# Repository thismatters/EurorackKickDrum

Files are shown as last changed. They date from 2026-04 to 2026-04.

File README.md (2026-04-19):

# Kick Drum

The circuit here is an implementation the circuit in the [Moritz Klien kick drum video](https://www.youtube.com/watch?v=yz37Yz315eU) with all of the trappings to make it a proper module. The aforementioned video is extremely good and deserves a watch (along with all their other content, top notch). While the [Erica Synths kit](https://www.ericasynths.lv/shop/diy-kits-1/edu-diy-kick-drum/) has 7 knobs I have limited myself to 4 knobs: Decay, Pitch, Distortion, and Tone. The other 3 knobs are be present as screw-turn potentiometers accessible from the front panel for retuning the module.

The KiCAD project here uses the library/footprints [found in my companion repo](https://github.com/thismatters/EurorackKiCAD).

## Width

6hp on a standard 3U rack.

## Inputs

3 Jacks
- Gate
- Accent CV
- Pitch CV

4 Knobs:
- Decay
- Distortion
- Tone
- Pitch

3 Screw Pots (accessible from front):
- Tune Decay
- Tune Depth
- Max Pitch CV

## Outputs

1 Jack for audio output.

## Vendors

There are part numbers in the [BOM](kick-drum.csv) for many of the parts (not for basic passives though) at the following vendors:

* [Mouser](https://www.mouser.com): Needs no introduction. Get your ICs from here (or [digikey](https://www.digikey.com)).
* [Tayda Electronics](https://www.taydaelectronics.com/): Good supplier for passive components; audio jacks, and potentiometers. Their audio jacks are slightly smaller than the thonkiconn from thonk.
* [Love My Switches](https://lovemyswitches.com/): Has [really good knobs](https://lovemyswitches.com/anodized-aluminum-knob-the-lo-fi-1-4-smooth-shaft-12-5mm-od/) to go on those potentiometers!
* [OSHPark](https://oshpark.com/): Fast and (relatively) cheap PCB manufacturer. Prototype run pending.

## Changelog

### V1
- [x] Fixed critical bug which shorted the bridged-T to the Tune depth chain.
- [x] Fixed footprint for Q2

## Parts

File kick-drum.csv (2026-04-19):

# | Reference | Qty | Value | Footprint | DNP | Vendor | PartNum | Note
1 | C1, C2 | 2 | 22u 50V | Capacitor_THT:CP_Radial_D5.0mm_P2.50mm
2 | C3 | 1 | 100n | Capacitor_SMD:C_0805_2012Metric
3 | C4 | 1 | 10n | Capacitor_SMD:C_0805_2012Metric
4 | C5, C6, C9 | 3 | 15n box | Capacitor_THT:C_Rect_L7.2mm_W3.5mm_P5.00mm_FKS2_FKP2_MKS2_MKP2
5 | C7 | 1 | 220n | Capacitor_SMD:C_0805_2012Metric
6 | C8 | 1 | 5.6n | Capacitor_SMD:C_0805_2012Metric
7 | C10 | 1 | 3.3n | Capacitor_SMD:C_0805_2012Metric
8 | D1, D2 | 2 | BAT54S | Package_TO_SOT_SMD:SOT-23 |  | Mouser | 863-BAT54SLT1G
9 | D3, D4, D5, D6, D7, D8, D9 | 7 | 1N4148 | Diode_SMD:D_SOD-323_HandSoldering
10 | J1 | 1 | Conn_02x05_Odd_Even | Eurorack:PinHeader_2x05_P2.54mm_Vertical |  | Tayda | A-2939
11 | J2 | 1 | GATE | Eurorack:AudioJack2_Tayda_A-2566 |  | Tayda | A-2566
12 | J3 | 1 | ACCENT CV | Eurorack:AudioJack2_Tayda_A-2566 |  | Tayda | A-2566
13 | J4 | 1 | PITCH CV | Eurorack:AudioJack2_Tayda_A-2566 |  | Tayda | A-2566
14 | J5 | 1 | OUTPUT | Eurorack:AudioJack2_Tayda_A-2566 |  | Tayda | A-2566
15 | Q1 | 1 | BCM857DS,135 | Package_SO:TSOP-6_1.65x3.05mm_P0.95mm
16 | Q2 | 1 | BC847 | Package_TO_SOT_SMD:SOT-23 |  | Mouser | 621-BC847C-13-F
17 | Q3 | 1 | BCM847DS,135 | Package_SO:TSOP-6_1.65x3.05mm_P0.95mm
18 | R1, R2 | 2 | 10 | Resistor_SMD:R_0805_2012Metric
19 | R3 | 1 | 39K | Resistor_SMD:R_0805_2012Metric
20 | R4, R20 | 2 | 33K | Resistor_SMD:R_0805_2012Metric
21 | R5, R6, R9, R15 | 4 | 100K | Resistor_SMD:R_0805_2012Metric
22 | R7 | 1 | 22K | Resistor_SMD:R_0805_2012Metric
23 | R8 | 1 | 120K | Resistor_SMD:R_0805_2012Metric
24 | R10 | 1 | 15K | Resistor_SMD:R_0805_2012Metric
25 | R11, R16 | 2 | 1M | Resistor_SMD:R_0805_2012Metric
26 | R12, R14, R22, R23 | 4 | 10K | Resistor_SMD:R_0805_2012Metric
27 | R13 | 1 | 2.2K | Resistor_SMD:R_0805_2012Metric
28 | R17, R18 | 2 | 47K | Resistor_SMD:R_0805_2012Metric
29 | R19 | 1 | 470K | Resistor_SMD:R_0805_2012Metric
30 | R21 | 1 | 1K | Resistor_SMD:R_0805_2012Metric
31 | RV1, RV7 | 2 | B100K | Eurorack:Potentiometer_RV16AF-41-15R1
32 | RV2 | 1 | 10K | Potentiometer_THT:Potentiometer_Bourns_3296W_Vertical
33 | RV3, RV4 | 2 | 100K | Potentiometer_THT:Potentiometer_Bourns_3296W_Vertical
34 | RV5 | 1 | B1M | Eurorack:Potentiometer_RV16AF-41-15R1
35 | RV6 | 1 | B50K | Eurorack:Potentiometer_RV16AF-41-15R1
36 | U1 | 1 | TL074 | Package_SO:SOIC-14_3.9x8.7mm_P1.27mm |  | Mouser | 595-TL074CDR

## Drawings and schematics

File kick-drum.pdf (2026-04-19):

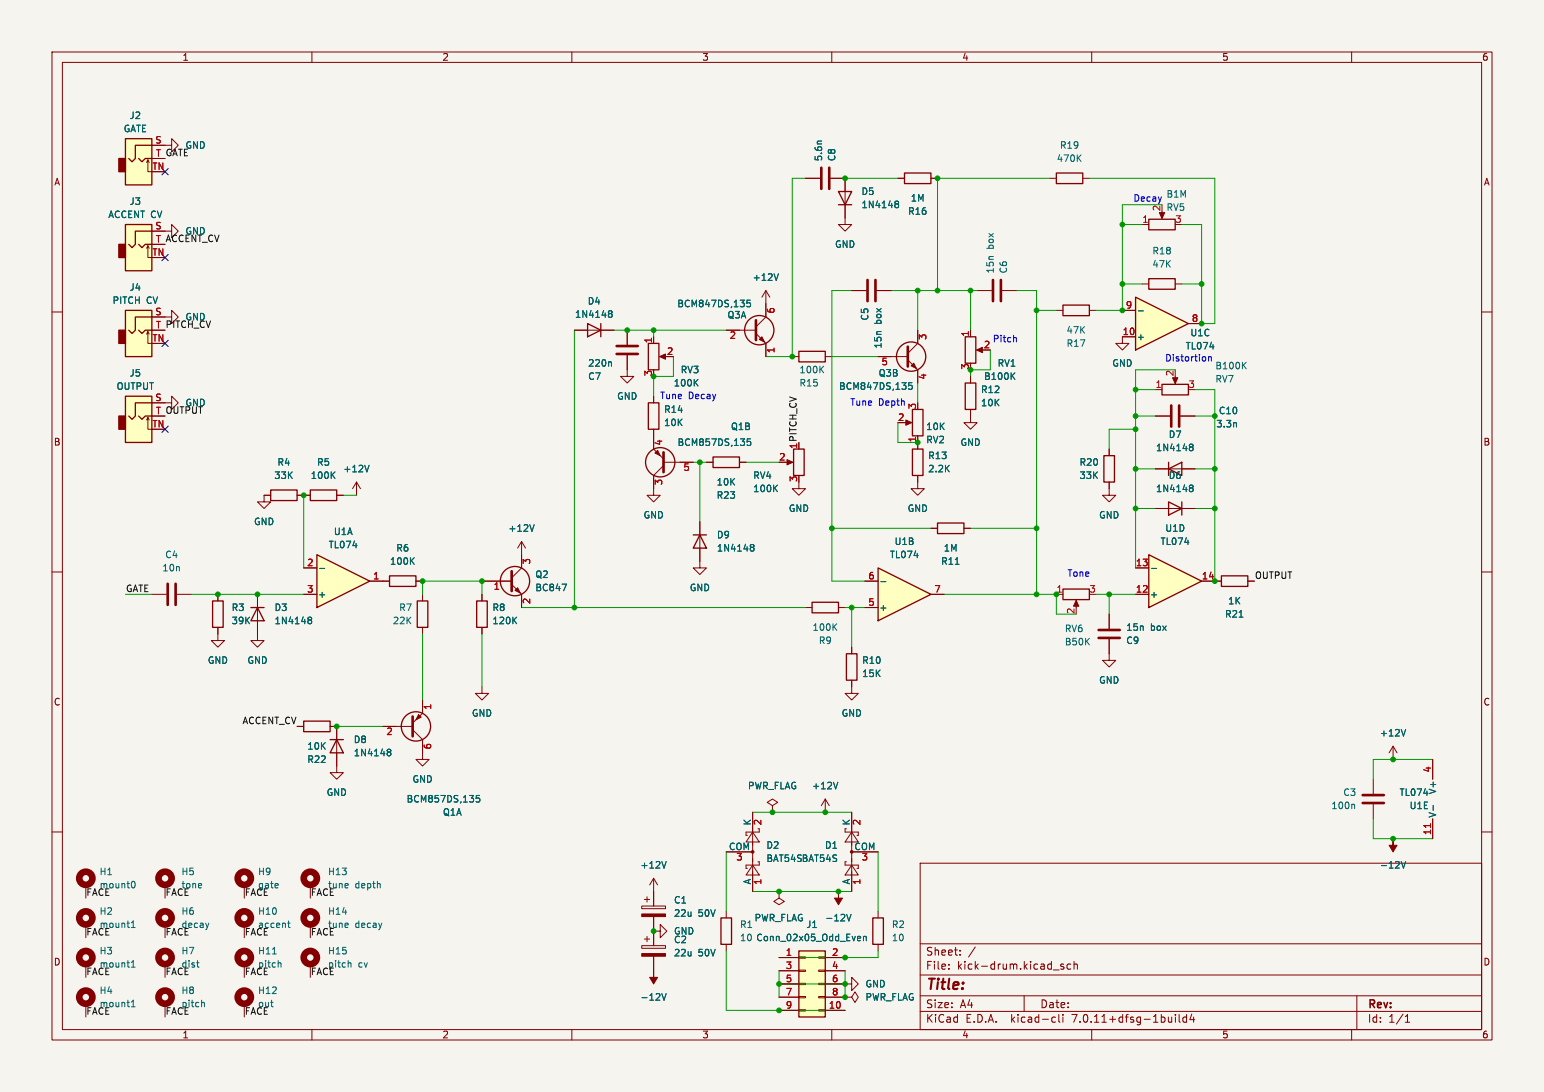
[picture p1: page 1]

Id: 1/1 Title: File: kick-drum.kicad_sch Sheet: / R1

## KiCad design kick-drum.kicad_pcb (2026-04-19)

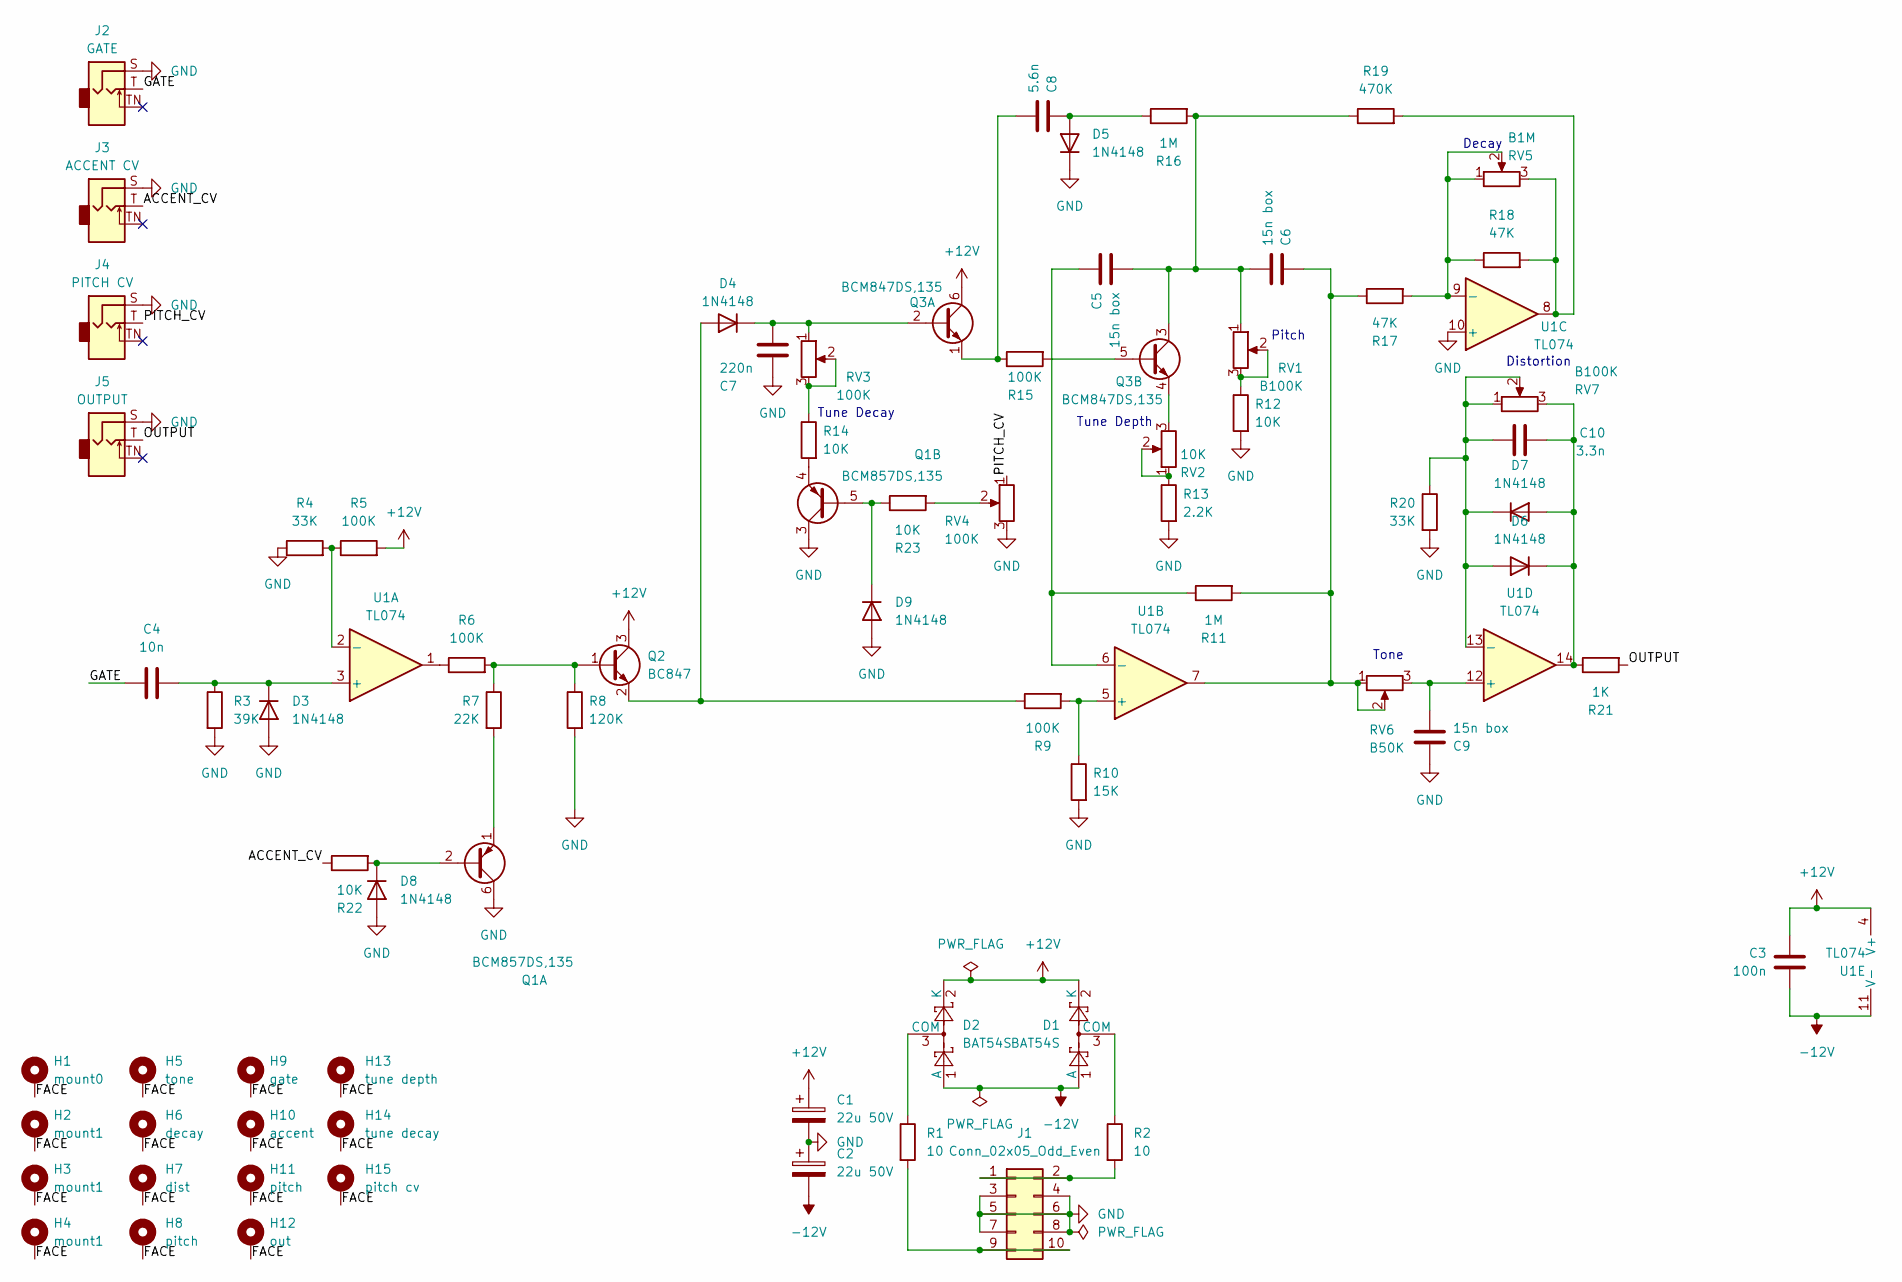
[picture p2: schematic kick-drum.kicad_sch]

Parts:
C1, C2: 22u 50V; CP_Radial_D5.0mm_P2.50mm
C3: 100n; C_0805_2012Metric
C4: 10n; C_0805_2012Metric
C5, C6, C9: 15n box; C_Rect_L7.2mm_W3.5mm_P5.00mm_FKS2_FKP2_MKS2_MKP2
C7: 220n; C_0805_2012Metric
C8: 5.6n; C_0805_2012Metric
C10: 3.3n; C_0805_2012Metric
D1, D2: BAT54S; SOT-23; PartNum 863-BAT54SLT1G
D3, D4, D5, D6, D7, D8, D9: 1N4148; D_SOD-323_HandSoldering
H1: mount0; Mech-MountingHole
H2, H3, H4: mount1; Mech-MountingHole
H5: tone; Mech-Potentiometer-Hole_level
H6: decay; Mech-Potentiometer-Hole_level
H7: dist; Mech-Potentiometer-Hole_level
H8: pitch; Mech-Potentiometer-Hole_level
H9: gate; Mech-AudioJack-Hole-Input-Gate
H10: accent; Mech-AudioJack-Hole-Input-CV
H11: pitch; Mech-AudioJack-Hole-Input-CV
H12: out; Mech-AudioJack-Hole-Output
H13: tune depth; Mech-LED-Hole-3mm
H14: tune decay; Mech-LED-Hole-3mm
H15: pitch cv; Mech-LED-Hole-3mm
J1: Conn_02x05_Odd_Even; PinHeader_2x05_P2.54mm_Vertical; PartNum A-2939
J2: GATE; AudioJack2_Tayda_A-2566; PartNum A-2566
J3: ACCENT CV; AudioJack2_Tayda_A-2566; PartNum A-2566
J4: PITCH CV; AudioJack2_Tayda_A-2566; PartNum A-2566
J5: OUTPUT; AudioJack2_Tayda_A-2566; PartNum A-2566
Q1: BCM857DS,135; TSOP-6_1.65x3.05mm_P0.95mm
Q2: BC847; SOT-23; PartNum 621-BC847C-13-F
Q3: BCM847DS,135; TSOP-6_1.65x3.05mm_P0.95mm
R1, R2: 10; R_0805_2012Metric
R3: 39K; R_0805_2012Metric
R4, R20: 33K; R_0805_2012Metric
R5, R6, R9, R15: 100K; R_0805_2012Metric
R7: 22K; R_0805_2012Metric
R8: 120K; R_0805_2012Metric
R10: 15K; R_0805_2012Metric
R11, R16: 1M; R_0805_2012Metric
R12, R14, R22, R23: 10K; R_0805_2012Metric
R13: 2.2K; R_0805_2012Metric
R17, R18: 47K; R_0805_2012Metric
R19: 470K; R_0805_2012Metric
R21: 1K; R_0805_2012Metric
RV1, RV7: B100K; Potentiometer_RV16AF-41-15R1
RV2: 10K; Potentiometer_Bourns_3296W_Vertical
RV3, RV4: 100K; Potentiometer_Bourns_3296W_Vertical
RV5: B1M; Potentiometer_RV16AF-41-15R1
RV6: B50K; Potentiometer_RV16AF-41-15R1
U1: TL074; SOIC-14_3.9x8.7mm_P1.27mm; PartNum 595-TL074CDR

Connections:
+12V: C1.1, C3.1, D1.2 (K), D2.2 (K), Q2.3 (C), Q3.6 (C1), R5.2, U1.4 (V+)
-12V: C2.2, C3.2, D1.1 (A), D2.1 (A), U1.11 (V-)
/ACCENT_CV: J3.T, R22.1
/FACE: H1.1, H2.1, H3.1, H4.1, H5.1, H6.1, H7.1, H8.1, H9.1, H10.1, H11.1, H12.1, H13.1, H14.1, H15.1
/GATE: C4.1, J2.T
/OUTPUT: J5.T, R21.2
/PITCH_CV: J4.T, RV4.1
GND: C1.2, C2.1, C7.1, C9.1, D3.2 (A), D5.1 (K), D8.2 (A), D9.2 (A), J1.3, J1.4, J1.5, J1.6, J1.7, J1.8, J2.S, J3.S, J4.S, J5.S, Q1.3 (C2), Q1.6 (C1), R3.2, R4.1, R8.2, R10.2, R12.2, R13.2, R20.2, RV4.3, U1.10 (+)
unnamed: C6.1, R11.2, R17.1, RV6.1, RV6.2, U1.7
unnamed: D1.3 (COM), R2.1
unnamed: D2.3 (COM), R1.1
unnamed: C4.2, D3.1 (K), R3.1, U1.3 (+)
unnamed: D4.2 (A), Q2.2 (E), R9.1
unnamed: C7.2, D4.1 (K), Q3.2 (B1), RV3.1
unnamed: C8.1, D5.2 (A), R16.1
unnamed: C10.2, D6.2 (A), D7.1 (K), R20.1, RV7.1, RV7.2, U1.13 (-)
unnamed: C10.1, D6.1 (K), D7.2 (A), R21.1, RV7.3, U1.14
unnamed: D8.1 (K), Q1.2 (B1), R22.2
unnamed: D9.1 (K), Q1.5 (B2), R23.1
unnamed: J1.1, J1.2, R2.2
unnamed: J1.9, J1.10, R1.2
unnamed: Q1.1 (E1), R7.2
unnamed: Q1.4 (E2), R14.2
unnamed: Q2.1 (B), R6.2, R7.1, R8.1
unnamed: C8.2, Q3.1 (E1), R15.1
unnamed: Q3.5 (B2), R15.2
unnamed: C5.2, C6.2, Q3.3 (C2), R16.2, R19.1, RV1.1
unnamed: Q3.4 (E2), RV2.3
unnamed: R6.1, U1.1
unnamed: R12.1, RV1.2, RV1.3
unnamed: R13.1, RV2.1, RV2.2
unnamed: R14.1, RV3.2, RV3.3
unnamed: R18.2, R19.2, RV5.3, U1.8
unnamed: R23.2, RV4.2
unnamed: R4.2, R5.1, U1.2 (-)
unnamed: R9.2, R10.1, U1.5 (+)
unnamed: C5.1, R11.1, U1.6 (-)
unnamed: R17.2, R18.1, RV5.1, RV5.2, U1.9 (-)
unnamed: C9.2, RV6.3, U1.12 (+)

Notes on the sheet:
Tune Decay
Tune Depth
Distortion
Pitch
Tone
Decay

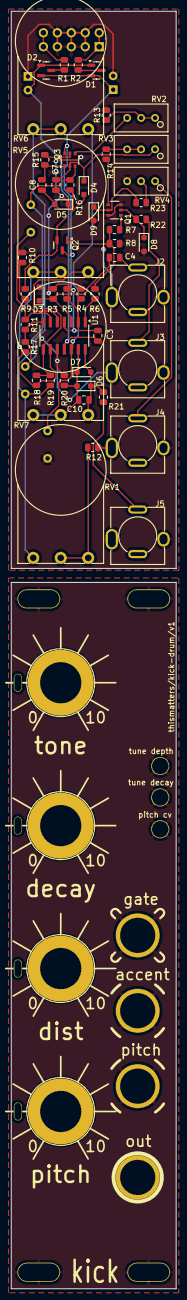
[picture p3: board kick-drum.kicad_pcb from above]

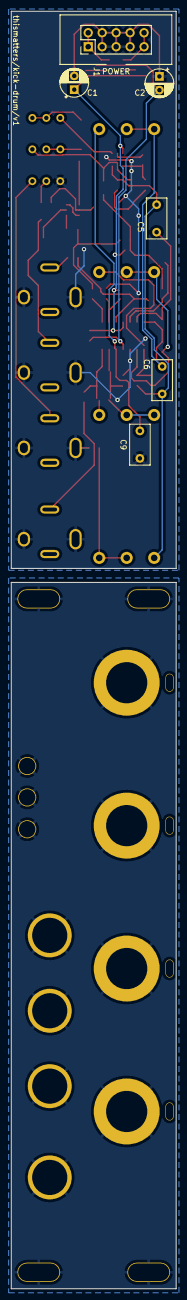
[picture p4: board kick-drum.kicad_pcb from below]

Board: 2 copper layers, 30.0 x 232.4 mm, 73 parts (6 on the bottom side), 39 nets.

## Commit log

2025-12-29 update footprints
    [kick-drum.csv, kick-drum.kicad_sch]
2025-12-31 update 15n caps to box type
    [kick-drum.csv, kick-drum.kicad_sch]
2025-12-31 bill of materials updates
    [kick-drum.csv, kick-drum.kicad_sch]
2026-01-06 prelim board layout
    [kick-drum.kicad_pcb, kick-drum.kicad_sch]
2026-01-11 v0 ready
    [kick-drum.csv, kick-drum.kicad_pcb, kick-drum.kicad_sch]
2026-01-31 prefab checklist v0
    [kick-drum.kicad_pcb]
2026-02-01 adding CV input protection
    [kick-drum.csv, kick-drum.kicad_sch]
2026-02-01 update PCB for input protection
    [kick-drum.kicad_pcb]
2026-04-19 v1 ready
    [kick-drum.csv, kick-drum.kicad_pcb, kick-drum.kicad_sch]
2026-04-19 include new schematic
